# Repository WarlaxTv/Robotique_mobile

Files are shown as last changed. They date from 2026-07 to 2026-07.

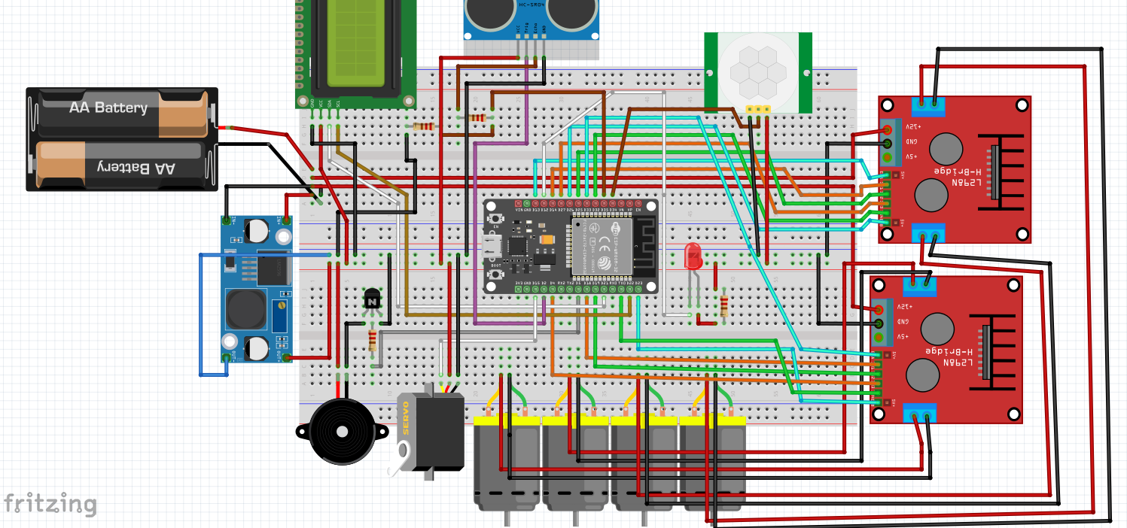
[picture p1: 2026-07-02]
plans-elec/schema-electronique.png

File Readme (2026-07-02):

# Robot Mobile Autonome

Robot mobile autonome à 4 roues basé sur ESP32, développé en C++ avec PlatformIO.

## Composants
- ESP32 MH-ET LIVE MiniKit
- 4× Moteurs DC + 2× Driver L298N
- HC-SR04 (ultrason) monté sur servo SG90
- HC-SR501 (PIR)
- Écran OLED 0.91" SSD1306

## Structure du repo
- code/        → Code source PlatformIO (C++)
- plans-3d/    → Fichiers CAO 
- docs/        → Document technique
- plans-elec   → Fichiers Fritzing

## Environnement de développement
- PlatformIO + Arduino framework
- Board : MH ET LIVE ESP32MiniKit
- Langage : C++

## Fonctionnement
Le robot utilise une machine à états finis (FSM) à 3 états :
- **MOVING** : déplacement libre, balayage ultrason via servo
- **TURNING** : virage à droite si obstacle < 15 cm
- **STOPPED** : arrêt d'urgence si mouvement détecté (PIR)

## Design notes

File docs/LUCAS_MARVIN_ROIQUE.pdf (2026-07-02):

Document Technique — Robot Mobile Autonome | ESP32 / PlatformIO / C++

# ROBOT MOBILE AUTONOME

## Document Technique

ESP32 • PlatformIO • C++ • FSM

Auteur : Lucas OGER-DOINEAU Marvin Lorenzo KAMDMEM KAMGANG Roique NGOUANA
Formation : Bachelor Robotique & Systèmes Embarqués — YNOV Bordeaux Date : 02/07/2026

### 1. Présentation générale du projet

Le Robot Mobile Autonome est un système embarqué à 4 roues conçu pour naviguer de façon autonome dans un environnement inconnu / connu. Il repose sur un microcontrôleur ESP32, deux drivers de moteurs L298N, un capteur ultrasonique monté sur servomoteur pour le balayage de l'environnement, et un capteur PIR pour la détection de présence humaine.
Le comportement du robot est régi par une machine à états finis (FSM) à trois états distincts : déplacement libre (MOVING), évitement d'obstacle (TURNING), et arrêt d'urgence (STOPPED). L'ensemble est développé en C++ avec le framework Arduino sous PlatformIO, dans une architecture multi-fichiers orientée composants.

### 1.1 Objectifs fonctionnels

- Se déplacer librement en avant en l'absence d'obstacle
- Détecter les obstacles via un capteur ultrasonique monté sur servo en balayage
- Effectuer un virage à droite automatique lors de la détection d'un obstacle (< 15 cm)
- S'arrêter immédiatement en cas de détection de mouvement humain (capteur PIR)
- Afficher l'état courant sur un écran OLED embarqué
- Permettre une extension Bluetooth pour le pilotage manuel (perspective future)

### 2. Architecture matérielle

### 2.1 Schéma bloc général

Le diagramme ci-dessous représente l'architecture matérielle complète du robot, depuis l'alimentation jusqu'aux actionneurs et capteurs :

┌─────────────────────────────────────────────────────────────────┐
│ | ALIMENTATION | │
│ ┌──────────────┐ | ┌──────────────────┐ | │
│ │ Li-Po 11,1V │───►│ | Step-down 5V / 3A │──► Rails 5V | │
│ │ 5,2 K mAh | │ | └──────────────────┘ | (moteurs/drivers) │
│ └──────────────┘ | │ | │
│ | └──────────────────────────────────►│
│ | 3.3V via régulateur ESP32 | │
└─────────────────────────────────────────────────────────────────┘ │
┌─────────────▼────────────────┐
│ | ESP32 MH-ET LIVE MiniKit | │
│ | (240 MHz / 320KB RAM) | │
└──┬────────┬────────┬─────────┘
┌────────────┘ | │ | └────────────────────┐
▼ | ▼ | ▼
┌───────────────┐ | ┌─────────────────┐ | ┌─────────────────┐
│ Bus I2C | │ | │ | GPIO digitaux │ | │ | GPIO PWM | │
│ SDA=21/SCL=22│ | │ | IN1..IN8 | │ | │ | ENA..END | │
└───────┬───────┘ | │ | TRIG, ECHO | │ | │ | Servo SG90 | │
│ | │ | PIR OUT | │ | └─────────────────┘
▼ | └───────┬─────────┘
┌───────────────┐ | │
│ OLED 0.91" | │ | ▼
│ SSD1306 | │ | ┌──────────────────────────────────────────┐
│ 128×32 px | │ | │ Actionneurs / Capteurs | │
└───────────────┘ | │ HC-SR04 │ HC-SR501 │ 4×DC │ 2×L298N | │
└──────────────────────────────────────────┘

### 2.2 Liste des composants

Composant | Référence | Rôle | Qtité
Microcontrôleur | ESP32 MH-ET LIVE MiniKit | Cerveau du robot, WiFi/BT intégré | 1
Moteur DC | Moteur DC 3-6V | Propulsion du robot | 4
Driver moteur | L298N dual H-Bridge | Pilotage des moteurs DC | 2
Capteur ultrason | HC-SR04 | Détection d'obstacles (distance) | 1
Capteur PIR | HC-SR501 | Détection de mouvement infrarouge | 1
Servomoteur | SG90 | Balayage du capteur ultrason | 1
Écran OLED | 0.91" 128×32 I2C (SSD1306) | Affichage état du robot | 1
Batterie | Li-PO 11,1V / 5,2 K mAh | Alimentation du robot | 1
Régulateur | Module step-down 5V | Conversion 12 V→5V pour moteurs/drivers | 1

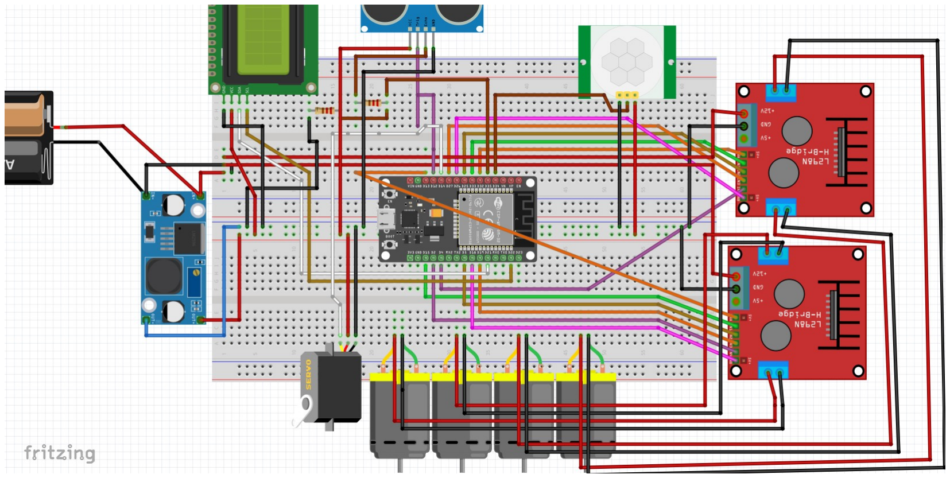
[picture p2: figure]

### 3. Assignation des pins (GPIO mapping)

Toutes les affectations de pins sont centralisées dans le fichier include/config.h. Cette approche garantit qu'une modification de câblage se répercute automatiquement sur tout le code sans avoir à chercher dans chaque fichier source.

Composant | Signal | GPIO ESP32 | Type | Remarque
SG90 Servo | Signal PWM | GPIO 14 | OUTPUT | Fix LEDC : delay(50) après attach()
OLED SSD1306 | SDA | GPIO 21 | I2C | Bus I2C partagé
OLED SSD1306 | SCL | GPIO 22 | I2C | Bus I2C partagé
HC-SR04 | TRIG | GPIO 12 | OUTPUT | Pin strapping — ok après boot
HC-SR04 | ECHO | GPIO 35 | INPUT ONLY | Pont diviseur
HC-SR501 PIR | OUT | GPIO 34 | INPUT ONLY | Calibration 30-60s au boot
L298N n°1 — Moteur A | ENA | GPIO 32 | OUTPUT | Enable moteur A
L298N n°1 — Moteur A | IN1 | GPIO 33 | OUTPUT | Direction A
L298N n°1 — Moteur A | IN2 | GPIO 25 | OUTPUT | Direction A
L298N n°1 — Moteur B | ENB | GPIO 26 | OUTPUT | Enable moteur B
L298N n°1 — Moteur B | IN3 | GPIO 27 | OUTPUT | Direction B
L298N n°1 — Moteur B | IN4 | GPIO 4 | OUTPUT | Direction B
L298N n°2 — Moteur C | ENC | GPIO 13 | OUTPUT | Enable moteur C
L298N n°2 — Moteur C | IN5 | GPIO 15 | OUTPUT | Direction C
L298N n°2 — Moteur C | IN6 | GPIO 5 | OUTPUT | Direction C
L298N n°2 — Moteur D | END | GPIO 18 | OUTPUT | Enable moteur D
L298N n°2 — Moteur D | IN7 | GPIO 19 | OUTPUT | Direction D
L298N n°2 — Moteur D | IN8 | GPIO 2 | OUTPUT | LED bleue intégrée sur GPIO2

Points d'attention spécifiques
- GPIO35 et GPIO34 sont des pins input-only sur l'ESP32 — ils ne peuvent jamais être configurés en OUTPUT. Ils conviennent parfaitement pour ECHO et PIR qui n'ont besoin que de lire un signal.
- GPIO12 est une pin strapping (MTDI) qui influence la tension flash au boot. Elle peut être utilisée comme GPIO normal une fois le démarrage terminé, mais il faut éviter de la tirer fortement au démarrage.
- GPIO2 est câblé en interne à la LED bleue de la carte MH-ET LIVE. Son utilisation pour IN8 entraîne un clignotement de cette LED synchronisé avec les commandes moteur D — sans impact fonctionnel.
- GPIO1 (TX0) et GPIO3 (RX0) sont réservés à la communication série USB — ne jamais les utiliser pour d'autres fonctions.

### 4. Analyse fonctionnelle — Machine à états finis (FSM)

### 4.1 Diagramme des états

Le comportement du robot est décrit par une FSM à 3 états. Le capteur PIR est évalué en priorité absolue à chaque itération de la boucle principale, avant tout autre traitement :

┌─────────────────────────────────────┐
│ | DÉMARRAGE | │
│ | Init moteurs / capteurs / OLED | │
└──────────────┬──────────────────────┘ │
▼
┌──────────────────────────────────────┐
┌────────►│ | ÉTAT : MOVING | │◄─────────────────┐
│ | │ • 4 moteurs en avant | │ | │
│ | │ • Servo balaye (0° → 180°) | │ | │
│ | │ • Lecture HC-SR04 à chaque pas | │ | │
│ | └────────────┬──────────┬──────────────┘ | │
PIR=0 │ | │ | │ | │
(reprise) | dist<15cm | PIR=1 | voie libre
│ | │ | │ | (dist≥15cm)
│ | ▼ | ▼ | │
│ | ┌────────────────┐ | ┌──────────────────────────┐ | │
└─────────┤ ÉTAT : STOPPED │ | │ | ÉTAT : TURNING | │────────┘
│ • stopAll() | │ | │ • turnRight() 800ms | │
│ • PIR détecté │ | │ • Re-mesure distance | │
│ • Affiche OLED │ | │ • Si encore bouché → | │
└────────────────┘ | │ | re-virer | │
└──────────────────────────┘

### 4.2 Description des états

MOVING — Déplacement libre
- Les 4 moteurs DC avancent en simultané
- Le servo SG90 balaye de 0° à 180° par pas de 5°, en rebondissant aux extrémités
- À chaque pas du servo, une mesure de distance est effectuée par le HC-SR04
- Si distance < 15 cm → transition vers TURNING
- Si PIR détecte un mouvement → transition vers STOPPED (prioritaire)

TURNING — Virage à droite
- Les moteurs du côté gauche avancent, les moteurs du côté droit reculent (pivot sur place)
- Le virage dure 800 ms (paramètre TURN_DURATION_MS réglable dans config.h)
- Après le virage, une nouvelle mesure de distance est effectuée
- Si la voie est libre (distance ≥ 15 cm) → retour à MOVING
- Si toujours obstrué → nouveau virage de 800 ms

STOPPED — Arrêt d'urgence
- Tous les moteurs sont stoppés immédiatement (stopAll())
- L'écran OLED affiche 'ARRET / Mouvement PIR!'
- Le robot reste immobile tant que le PIR détecte du mouvement
- Dès que le PIR repasse à LOW → retour automatique à MOVING

### 4.3 Paramètres configurables (config.h)

Constante | Valeur défaut | Rôle
OBSTACLE_THRESHOLD_CM | 15 cm | Seuil de détection d'obstacle
SERVO_MIN / SERVO_MAX | 0° / 180° | Amplitude de balayage du servo
SERVO_STEP | 5° | Pas de balayage (finesse de détection)
SERVO_DELAY_MS | 30 ms | Délai stabilisation servo avant mesure
TURN_DURATION_MS | 800 ms | Durée du virage à droite

### 5. Architecture logicielle

### 5.1 Structure des fichiers

Le projet suit une architecture multi-fichiers orientée composants, où chaque module physique correspond à une classe C++ dédiée. Cette approche garantit la lisibilité, la maintenabilité et la réutilisabilité du code.

ROBOT_MOBILE/
├── platformio.ini | ← Configuration build/libs/board
├── include/
│ | └── config.h | ← TOUS les GPIO centralisés (seul fichier à modifier)
├── lib/
│ | ├── MotorDriver/ | ← Pilotage 4 moteurs DC via 2× L298N
│ | │ | ├── MotorDriver.h
│ | │ | └── MotorDriver.cpp
│ | ├── UltrasonicSensor/ | ← HC-SR04 (mesure de distance)
│ | │ | ├── UltrasonicSensor.h
│ | │ | └── UltrasonicSensor.cpp
│ | ├── PIRSensor/ | ← HC-SR501 (détection de mouvement)
│ | │ | ├── PIRSensor.h
│ | │ | └── PIRSensor.cpp
│ | ├── OledDisplay/ | ← Écran OLED 0.91" SSD1306 I2C
│ | │ | ├── OledDisplay.h
│ | │ | └── OledDisplay.cpp
│ | └── GateServo/ | ← Servomoteur SG90
│ | ├── GateServo.h
│ | └── GateServo.cpp
└── src/
└── main.cpp | ← FSM + orchestration (aucune logique bas niveau)

### 5.2 Principe de séparation des responsabilités

- Chaque classe expose uniquement des méthodes métier (ex: motors.forward(), oled.showMessage()) — aucun digitalWrite() ne traîne dans main.cpp
- config.h est le seul point de vérité pour les pins : modifier un GPIO ne nécessite de toucher qu'à ce fichier
- main.cpp se lit comme un cahier des charges : les actions sont lisibles en français fonctionnel, pas en détails électroniques
- Les librairies tierces (ESP32Servo, Adafruit SSD1306) sont déclarées uniquement dans platformio.ini via lib_deps — PlatformIO les télécharge automatiquement

### 6. Alimentation, consommation et autonomie

### 6.1 Bilan de consommation

Le tableau suivant présente les consommations typiques et maximales de chaque composant du robot. Les valeurs sont issues des datasheets constructeurs et de mesures empiriques communautaires.

Composant | Tension (V) | Courant typ. (mA) | Courant max (mA) | Source
ESP32 | 3.3 | 80 | 250 | 3.3V régulateur interne
OLED SSD1306 | 3.3 | 20 | 30 | 5V step-down
HC-SR04 | 5.0 | 15 | 20 | 5V step-down
HC-SR501 PIR | 5.0 | 65 | 65 | 5V step-down
SG90 (idle) | 5.0 | 10 | 600 | 5V step-down
Moteur DC × 4 | 5.0 | 1200 | 2 – 3,2 kA | L298N
L298N × 2 (logique) | 5.0 | 72 | 100 | 5V step-down (2×36mA)
TOTAL ESTIMÉ | — | 1462 | 4265 | —

### 6.2 Calcul de l'autonomie

Hypothèses de calcul
- Batterie : Li-PO → 11,1V / 5200 mAh (configuration minimale)
- Rendement du convertisseur step-down 5V : 85 %
- Profil d'utilisation : 70% MOVING (moteurs à charge partielle), 10% TURNING, 20% STOPPED

Courant moyen selon profil :
I_moy = (0.70 × 1200) + (0.10 × 800) + (0.20 × 262) = 840 + 80 + 52 = 972 mA

Courant réel tiré de la batterie :
I_batterie = (I_moy × 5V) / (7.4V × 0.85) = (972 × 5) / 6.29 ≈ 773 mA

Autonomie estimée :
T = Capacité / I_batterie = 5200 mAh / 773 mA ≈ 6h45 min environ.

### 7. Perspective : Contrôle via Bluetooth (BLE/BT Classic)

### 7.1 Motivation et intérêt

L'ESP32 intègre nativement un module Bluetooth 4.2 (BT Classic + BLE) ainsi que le WiFi 802.11 b/g/n, sans nécessiter de composant externe. Cette capacité constitue une extension naturelle du projet pour permettre un pilotage manuel ou semi-automatique du robot depuis un smartphone ou une application dédiée. L'intégration Bluetooth ne modifie pas le câblage existant — aucune pin supplémentaire n'est requise.

### 7.2 Modes de contrôle envisagés

Mode Bluetooth Classic (SPP — Serial Port Profile)
- Émulation d'un port série sans fil via la lib BluetoothSerial.h (incluse dans le framework Arduino ESP32)
- Compatible avec les applications Android/iOS de type 'Serial Bluetooth Terminal'
- Commandes textuelles simples : F (forward), B (backward), R (right), L (left), S (stop), A (auto)
- Facilement intégrable dans l'architecture FSM existante via un nouvel état MANUAL

Mode BLE (Bluetooth Low Energy)
- Consommation réduite par rapport au BT Classic — adapté à une utilisation sur batterie
- Utilisation de la lib NimBLE-Arduino pour une empreinte mémoire minimale
- Permet la communication avec des applications Flutter/React Native pour une interface personnalisée

### 7.3 Architecture FSM étendue avec Bluetooth

┌───────────────────────────────────┐
│ | DÉMARRAGE | │
│ + Init BluetoothSerial | │
└──────────────┬────────────────────┘ │
┌──────────────▼──────────────────────┐
┌────────►│ | ÉTAT : MOVING | │
│ | │ (comportement autonome inchangé) | │
│ | └──────────┬────────────┬─────────────┘
│ | │ | │
│ | cmd BT reçue | PIR / obstacle
│ | │ | │
│ | ┌──────────▼──┐ | ┌────▼─────────┐
cmd='A' | │ | MANUAL | │ | │ TURNING / | │
(retour auto) | │ Commandes | │ | │ STOPPED | │
│ | │ manuelles | │ | │ (inchangés) │
└─────────┤ BT temps | │ | └──────────────┘
│ réel | │
└─────────────┘

### 7.4 Extrait de code d'intégration prévu

// Dans main.cpp — ajout minimal pour BT Classic #include <BluetoothSerial.h>
BluetoothSerial bt;

void setup() {
bt.begin("RobotMobile"); // nom visible au scan BT // ... reste de l'init ...
}

void loop() {

// Priorité BT si un opérateur envoie une commande if (bt.available()) {
char cmd = bt.read();
state = RobotState::MANUAL; handleManualCmd(cmd); // F/B/R/L/S/A }
// ... reste de la FSM ...
}

### 7.5 Contraintes et points d'attention

- BluetoothSerial et WiFi ne peuvent pas être actifs simultanément sur l'ESP32 (partage d'antenne RF) — pour une utilisation conjointe WiFi+BT, il faut utiliser BLE uniquement
- Le Bluetooth Classic consomme ~50-100 mA supplémentaires en transmission active — à intégrer dans le bilan d'autonomie
- La portée typique est de 10-30 mètres en champ libre selon les obstacles et les appareils
- Aucune pin GPIO supplémentaire n'est nécessaire — l'intégration est 100% logicielle

### 8. Conclusion et perspectives

Le Robot Mobile Autonome constitue une plateforme embarquée complète intégrant acquisition sensorielle, traitement temps réel, actionnement et interface homme-machine locale (OLED). L'architecture logicielle modulaire adoptée (FSM + classes par composant) permet une évolution aisée du projet sans remise en cause de l'existant. Les perspectives d'évolution identifiées à court et moyen terme sont les suivantes :
- Intégration du contrôle Bluetooth Classic pour le pilotage manuel via smartphone
- Ajout d'un algorithme de suivi de ligne ou de cartographie simple (SLAM basique)
- Remplacement des drivers L298N par des drivers plus efficaces (DRV8833) pour améliorer l'autonomie et réduire les pertes thermiques
- Ajout d'une caméra OV2640 compatible ESP32 pour la surveillance vidéo en temps réel via WiFi
- Migration vers un PID sur la vitesse des moteurs si des encodeurs sont ajoutés aux roues

Document rédigé dans le cadre du Bachelor Robotique & Systèmes Embarqués — YNOV Bordeaux

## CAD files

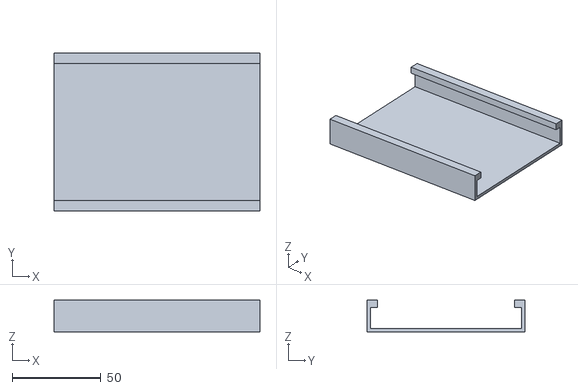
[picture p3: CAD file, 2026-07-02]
plans-3d/breadboard.STL
116.0 x 89.2 x 18.0

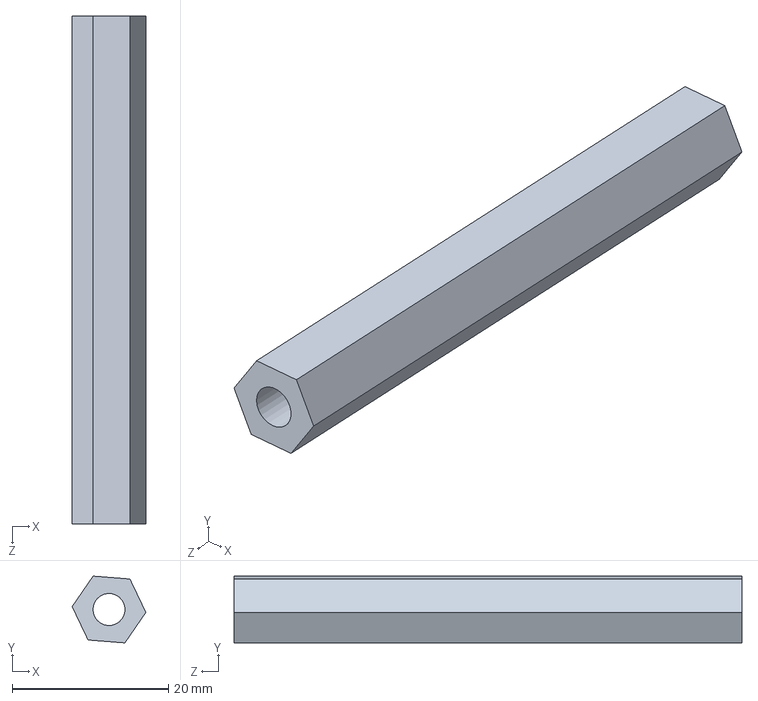
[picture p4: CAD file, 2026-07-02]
plans-3d/en tr.SLDPRT
9.44 x 8.55 x 65.0 mm

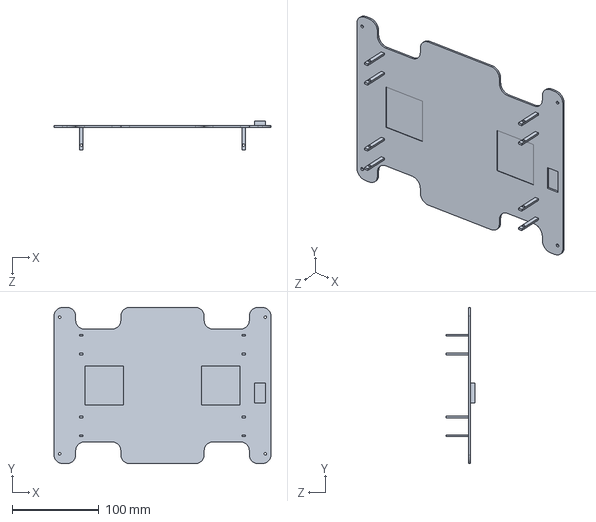
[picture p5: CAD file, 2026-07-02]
plans-3d/chassis base.SLDPRT
250.0 x 180.0 x 33.0 mm

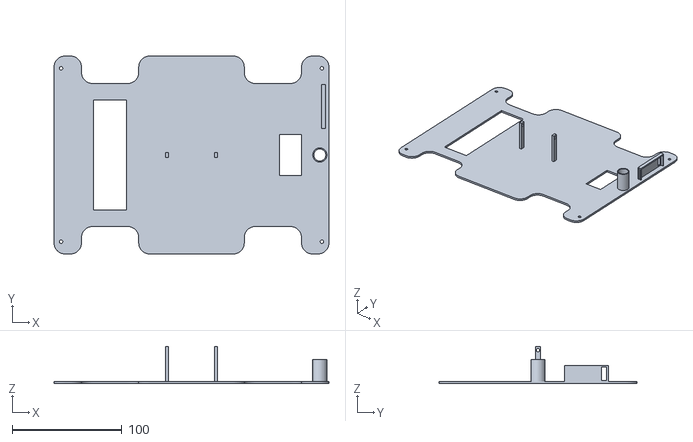
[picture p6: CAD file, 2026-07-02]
plans-3d/CHASSIS DESSUS.STL
250.0 x 180.0 x 34.0

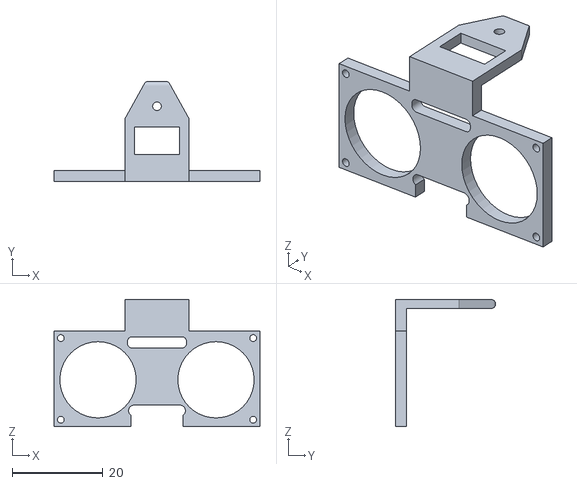
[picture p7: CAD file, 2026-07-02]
plans-3d/ultra.STL
45.4 x 22.1 x 28.0

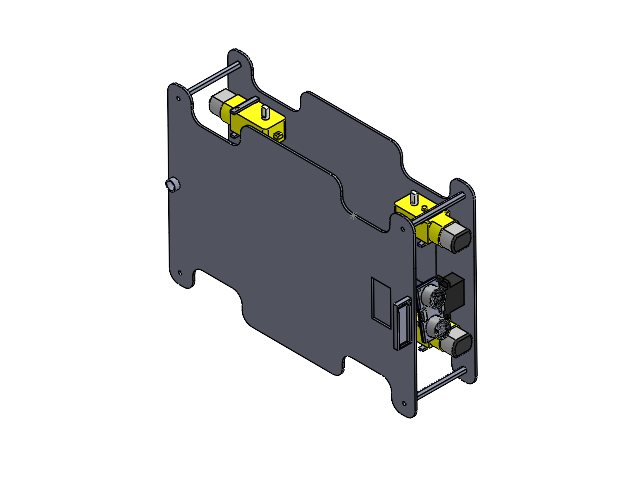
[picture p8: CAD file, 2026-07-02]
plans-3d/Assemblage1.SLDASM
servomoteur
projet robot mobile
capteur ultrason
assemblage
entretoise x 4
cache dessus
GearMotorTTRC x 4

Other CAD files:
plans-3d/ENTRETOISES.STL
plans-3d/cache dessus.SLDPRT

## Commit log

2026-07-02 Ajout plans 3D
    [Assemblage1.SLDASM, CHASSIS DESSUS.STL, ENTRETOISES.STL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]
2026-07-02 Ajout Plans électriques
    [schematicc-electronic.fzz]
2026-07-02 MAJ Plan-elec
    [schematicc-electronic.fzz]
